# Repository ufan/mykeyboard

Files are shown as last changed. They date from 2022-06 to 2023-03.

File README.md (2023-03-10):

# A collection of designed keyboards #
## Features
All keyboards are powered by [zmk](https://zmk.dev/) with following design goals:
- portability
- minimalism
- ergonomic
- yet still powerful

## Super-powerful trackball firmware
- [youtube trackball demo](https://www.youtube.com/watch?v=7J-NTVMHwWQ&t=86s)
- [pmw3610_breakout pcb](https://github.com/ufan/pmw3610_breakout)
- [firmware support](https://github.com/ufan/zmk/tree/ptdevice-refactor)

# 42-key classic Corne-Pro with EPD display
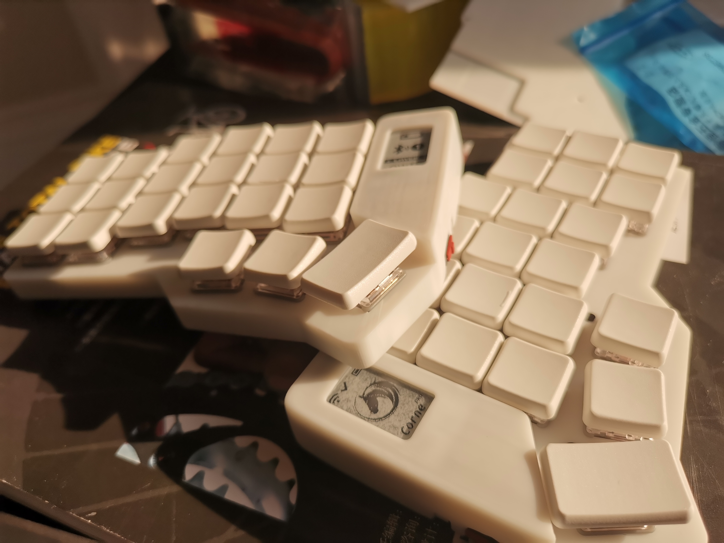
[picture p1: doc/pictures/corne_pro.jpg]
corne_pro


# 34-key Sweep-Pro with horizontal encoders
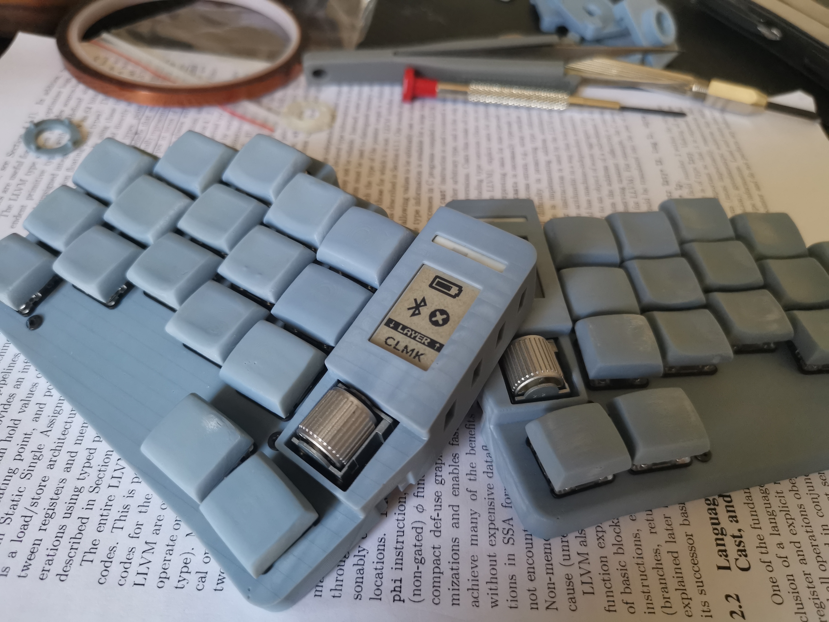
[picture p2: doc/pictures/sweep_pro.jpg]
sweep_pro


# 32-key Blade with a mini-trackball and a touchbar
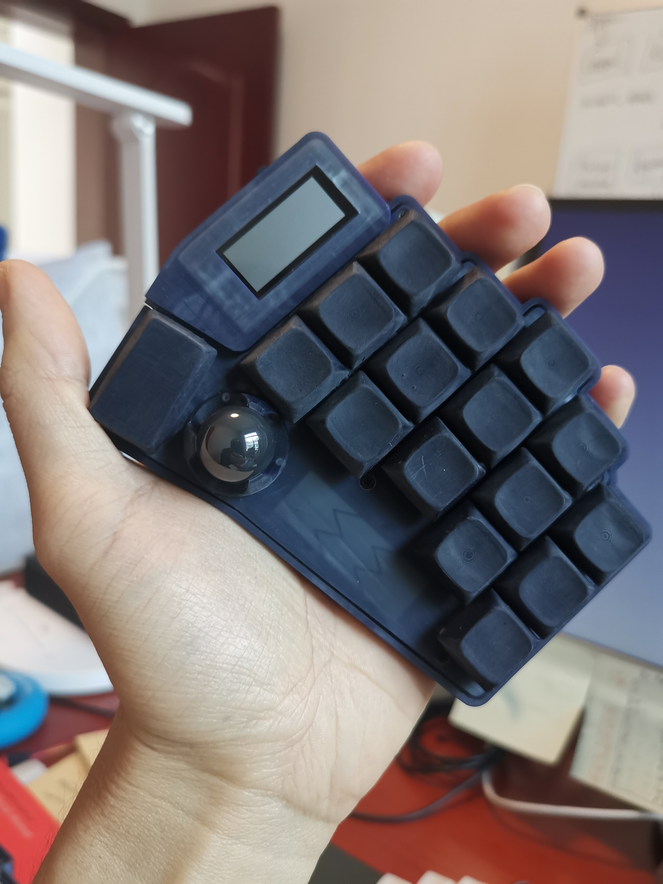
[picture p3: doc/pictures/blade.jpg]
blade


# Customizable logo display
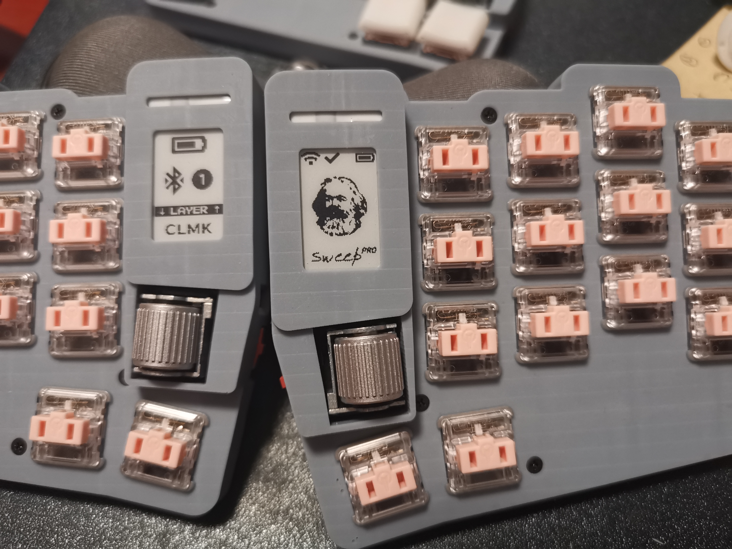
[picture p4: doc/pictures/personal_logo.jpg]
persoal_logo


# Wireless charging option
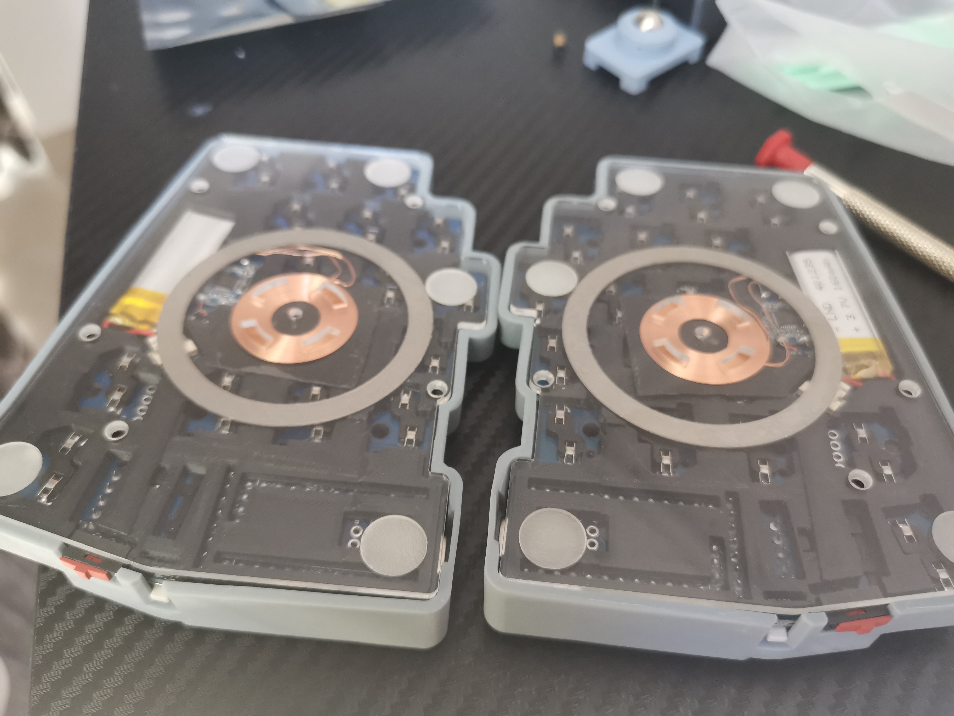
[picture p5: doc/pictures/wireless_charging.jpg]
wireless_charging


# Tenting support
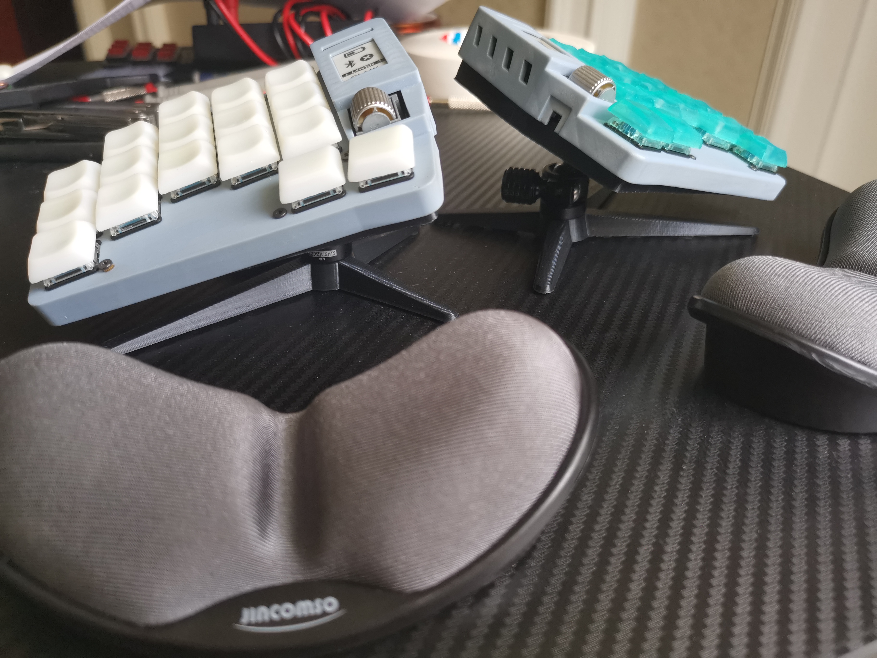
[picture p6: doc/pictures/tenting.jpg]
tenting


# Extensible
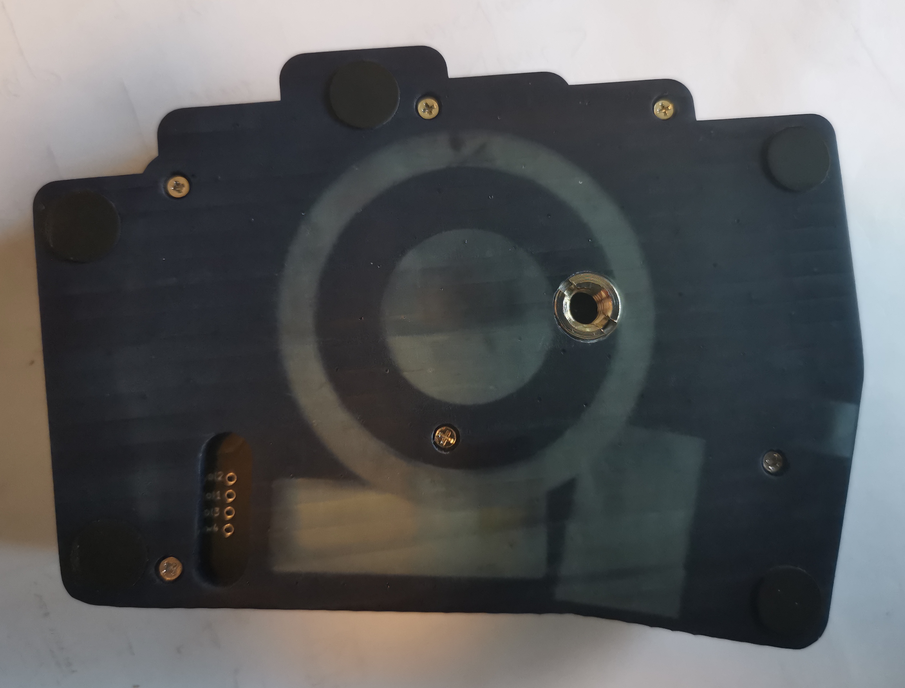
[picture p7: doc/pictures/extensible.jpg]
extensible


# 3D-printed concave/convex keycaps
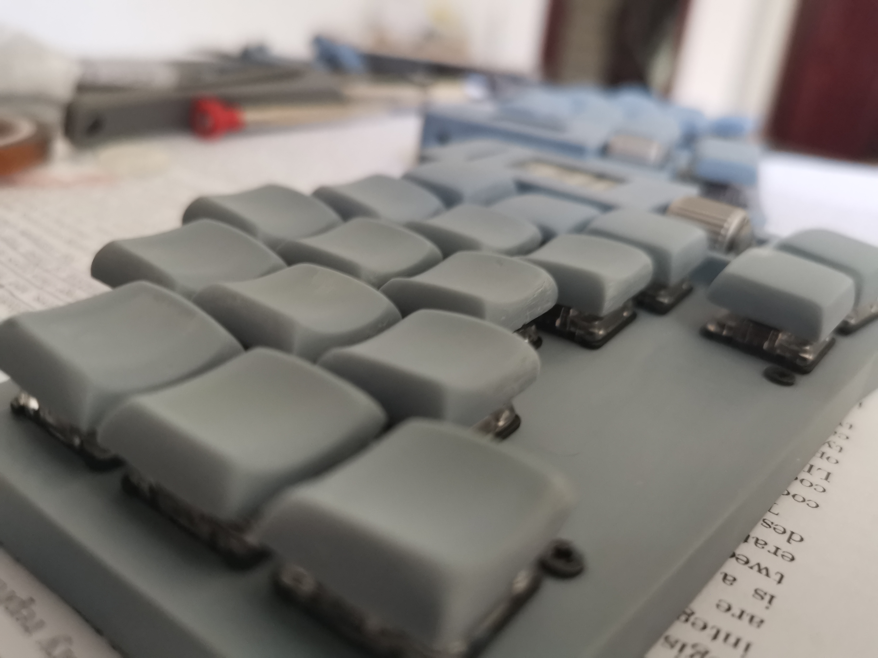
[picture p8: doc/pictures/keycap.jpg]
keycaps


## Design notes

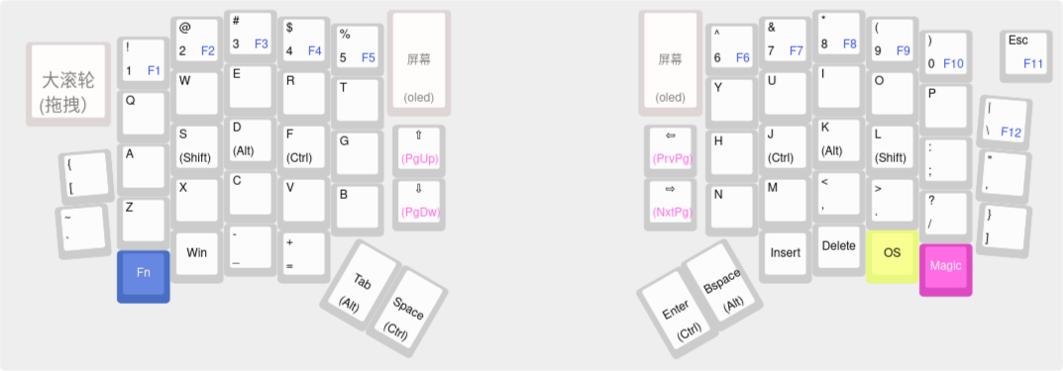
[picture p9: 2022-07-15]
doc/palm180/keyboard-layout.png

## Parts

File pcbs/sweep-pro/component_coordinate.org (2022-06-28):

* coordinates of each footprint
|                 |     left_x |    left_y |    delta_x |   delta_y |   right_x |   right_y |  angle |
|-----------------+------------+-----------+------------+-----------+-----------+-----------+--------|
| reference point |        212 |     43.75 |          0 |        0. | 82.754568 |     46.11 |        |
| pro micro       |        201 |    60.175 |        -11 |    16.425 | 93.754568 |    62.535 |        |
| display         |        201 |    79.275 |        -11 |    35.525 | 93.754568 |    81.635 |        |
| encoder         | 199.321127 | 93.163087 | -12.678873 | 49.413087 | 95.433441 | 95.523087 |    -95 |
| power_switch    |      209.7 |      96.9 |       -2.3 |     53.15 | 85.054568 |     99.26 | -103.4 |
| reset_button    |    211.825 |     86.45 |     -0.175 |      42.7 | 82.929568 |     88.81 |    -95 |
| sw1             |        107 |        67 |       -105 |     23.25 | 187.75457 |     69.36 |        |
| sw2             |        125 |        55 |        -87 |     11.25 | 169.75457 |     57.36 |        |
| sw3             |        143 |        48 |        -69 |      4.25 | 151.75457 |     50.36 |        |
| sw4             |        161 |      53.5 |        -51 |      9.75 | 133.75457 |     55.86 |        |
| sw5             |        179 |        56 |        -33 |     12.25 | 115.75457 |     58.36 |        |
| sw6             |        107 |        84 |       -105 |     40.25 | 187.75457 |     86.36 |        |
| sw7             |        125 |        72 |        -87 |     28.25 | 169.75457 |     74.36 |        |
| sw8             |        143 |        65 |        -69 |     21.25 | 151.75457 |     67.36 |        |
| sw9             |        161 |      70.5 |        -51 |     26.75 | 133.75457 |     72.86 |        |
| sw10            |        179 |        73 |        -33 |     29.25 | 115.75457 |     75.36 |        |
| sw11            |        107 |       101 |       -105 |     57.25 | 187.75457 |    103.36 |        |
| sw12            |        125 |        89 |        -87 |     45.25 | 169.75457 |     91.36 |        |
| sw13            |        143 |        82 |        -69 |     38.25 | 151.75457 |     84.36 |        |
| sw14            |        161 |      87.5 |        -51 |     43.75 | 133.75457 |     89.86 |        |
| sw15            |        179 |        90 |        -33 |     46.25 | 115.75457 |     92.36 |        |
| sw16            | 176.407158 |    110.95 | -35.592842 |      67.2 | 118.34741 |    113.31 |     -5 |
| sw17            | 195.367403 |    114.55 | -16.632597 |      70.8 | 99.387165 |    116.91 |    -13 |
| h1              |        115 |      57.5 |        -97 |     13.75 | 179.75457 |     59.86 |        |
| h2              |      171.2 |    46.425 |      -40.8 |     2.675 | 123.55457 |    48.785 |        |
| h3              |      187.3 |     101.6 |      -24.7 |     57.85 | 107.45457 |    103.96 |        |
| h4              |     116.95 |    108.15 |     -95.05 |      64.4 | 177.80457 |    110.51 |        |
| h5              |     165.35 |    114.93 |     -46.65 |     71.18 | 129.40457 |    117.29 |        |
| battery_switch  |      209.7 |      96.9 |       -2.3 |     53.15 | 85.054568 |     99.26 |    -103.4  |
| battery_con     |        167 |        99 |        -45 |     55.25 | 127.75457 |    101.36 |    130 |
| coil_con        |     155.85 |    98.025 |     -56.15 |    54.275 | 138.90457 |   100.385 | -98    |
| pogopin-1       |     202.54 |        53 |      -9.46 |      9.25 | 92.214568 |     55.36 |        |
| pogopin-2       |        200 |        53 |        -12 |      9.25 | 94.754568 |     55.36 |        |
| pogopin-3       |    178.625 |    100.35 |    -33.375 |      56.6 | 116.12957 |    102.71 |        |
#+TBLFM: $4=$2-@2$2::$5=$3-@2$3::$6=-$4+82.754568::$7=$5+46.11

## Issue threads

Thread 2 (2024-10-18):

A question about the pmw3610 cpi configuration.

klesh, 2024-10-18:
Hi, sorry to disturb you.

 I am working on porting the PMW3610 driver to QMK based on your implementation on https://github.com/ufan/zmk/tree/ptdevice-refactor/app/drivers/sensor/pixart/pmw3610
Your code looks solid and the mouse movement is working.
However, the `set_cpi` doesn't work on my side, I checked and rewrote the code many times and it just doesn't seem to be working 😂.
I don't know what to do next, mainly because I don't know how to verify if the CPI was configured correctly, here were my thoughts:
1. I suppose the cursor should move faster when the CPI is cranked up, but it didn't, the movement feels the same to me
2. Or I can read the sensor register to verify, but I don't know how to do so, because the datasheet doesn't mention it at all...

I wonder if you could help me with the following questions:

- Is `set_cpi` function working correctly for you? if so, is it moving faster when the CPI is higher?
- Do you know how to read the CPI register?
- I am designing a trackball using a snooker ball, when I roll the ball for a while, it would stop for few second then move again... like it needs a break or something, do you know why?

Here is my code if you would like to take a look:
https://github.com/klesh/vial-qmk/commit/7ee1826e2ec4768d11cb37462bd6b3debae2f722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

I am posting the issue here because `issues` on your `zmk` repo is disabled, hope you don't mind, and feel free to close it if you don't like it.

Thanks in advance.

klesh, 2024-10-18:
Ahh, I figured out what was wrong with the `set_cpi` code.

ufan, 2024-10-21:
Seems you've solved the problem. I did not test this function thoroughly. Did you mind posting a link to the corrected code?

klesh, 2024-10-21:
Sure, here you are. It is working nicely on my side:
https://github.com/klesh/vial-qmk/blob/319a4dc4122595aa557ad234925175cfb327d24c/drivers/sensors/pmw3610.c#L238

And I fixed the "cursor stop moving randomly" problem by forcing the sensor into awake mode
https://github.com/klesh/vial-qmk/blob/319a4dc4122595aa557ad234925175cfb327d24c/drivers/sensors/pmw3610.c#L238

Now, It is working fine most of the time. However, the cursor movement still goes haywire(moving slowly and flicking) sometimes, and I have to reset the MUC for it to work again. 😂

bullwinkle3000, 2024-12-05:
Hey there!  Curious if you got the haywire thing addressed at all?  Tested a bit on my side, and it seems to generally work well.

klesh, 2024-12-09:
@bullwinkle3000 I am not quite sure, but it seems like the haywire was caused by the hardware damage. Maybe I overheated them during the soldering.

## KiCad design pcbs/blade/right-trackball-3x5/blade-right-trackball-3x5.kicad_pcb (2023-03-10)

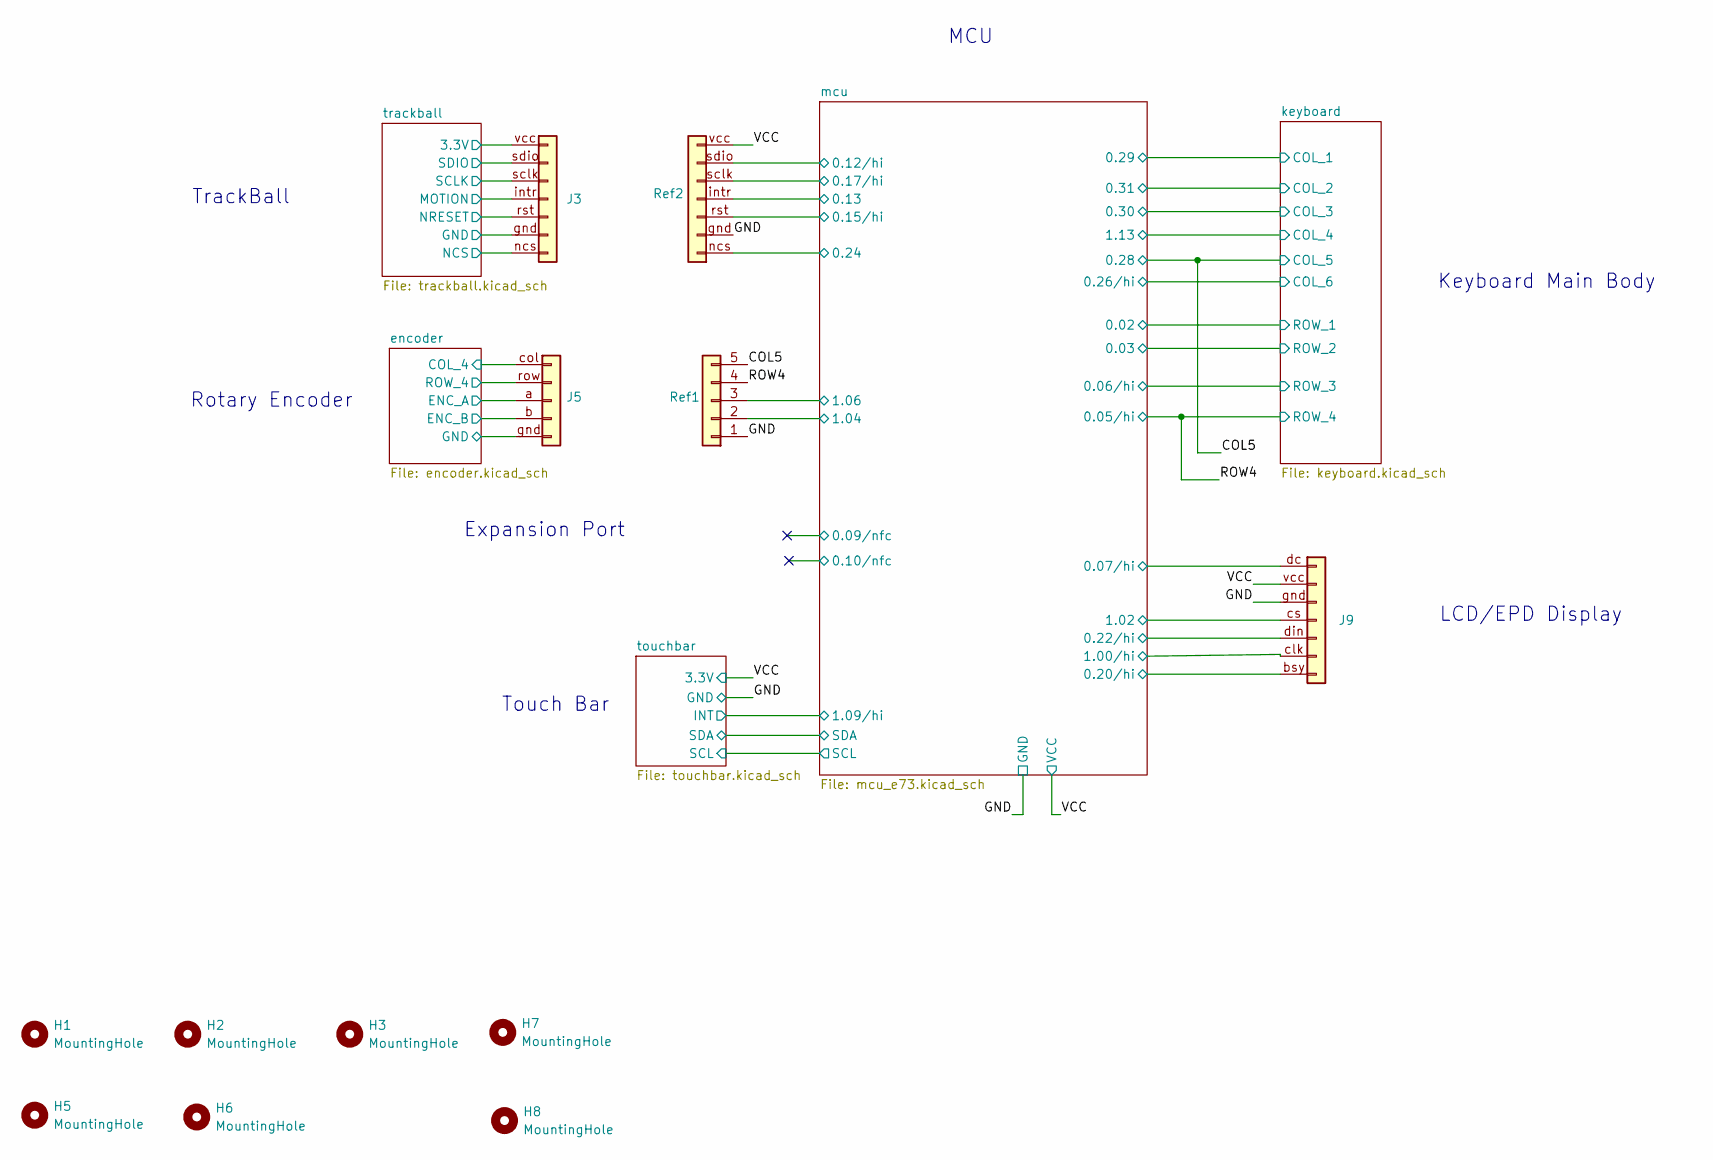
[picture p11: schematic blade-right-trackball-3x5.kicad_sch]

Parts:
H1, H2, H3, H5, H6, H7: MountingHole; MountingHole_3.2mm_M3_DIN965
H8: MountingHole; MountingHole_2mm
J3: Conn_01x07; PMW3610-Ref-Male
J5: Conn_01x05; Panasonic_EVQWGD001_Ref_Male
J9: Conn_Display_general; Conn_Display_MountHole
Ref1: Conn_01x05; Panasonic_EVQWGD001_Ref
Ref2: Conn_1x07; PMW3610-Ref

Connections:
/COL5: Ref1.5; also elsewhere on the board
/ROW4: Ref1.4; also elsewhere on the board
/VCC: J9.vcc, Ref2.vcc; also elsewhere on the board
/encoder/COL_4: J5.col; also elsewhere on the board
/encoder/ENC_A: J5.a; also elsewhere on the board
/encoder/ENC_B: J5.b; also elsewhere on the board
/encoder/GND: J5.gnd; also elsewhere on the board
/encoder/ROW_4: J5.row; also elsewhere on the board
/mcu/0.07/hi: J9.dc; also elsewhere on the board
/mcu/0.12/hi: Ref2.sdio; also elsewhere on the board
/mcu/0.13: Ref2.intr (motion); also elsewhere on the board
/mcu/0.15/hi: Ref2.rst; also elsewhere on the board
/mcu/0.17/hi: Ref2.sclk; also elsewhere on the board
/mcu/0.20/hi: J9.bsy; also elsewhere on the board
/mcu/0.22/hi: J9.din; also elsewhere on the board
/mcu/0.24: Ref2.ncs; also elsewhere on the board
/mcu/1.00/hi: J9.clk; also elsewhere on the board
/mcu/1.02: J9.cs; also elsewhere on the board
/mcu/1.04: Ref1.2; also elsewhere on the board
/mcu/1.06: Ref1.3; also elsewhere on the board
/trackball/3.3V: J3.vcc; also elsewhere on the board
/trackball/GND: J3.gnd; also elsewhere on the board
/trackball/MOTION: J3.intr (motion); also elsewhere on the board
/trackball/NCS: J3.ncs; also elsewhere on the board
/trackball/NRESET: J3.rst; also elsewhere on the board
/trackball/SCLK: J3.sclk; also elsewhere on the board
/trackball/SDIO: J3.sdio; also elsewhere on the board
GND: J9.gnd, Ref1.1, Ref2.gnd; also elsewhere on the board

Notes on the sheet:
Touch Bar
Rotary Encoder
LCD/EPD Display
Keyboard Main Body
Expansion Port
TrackBall
MCU

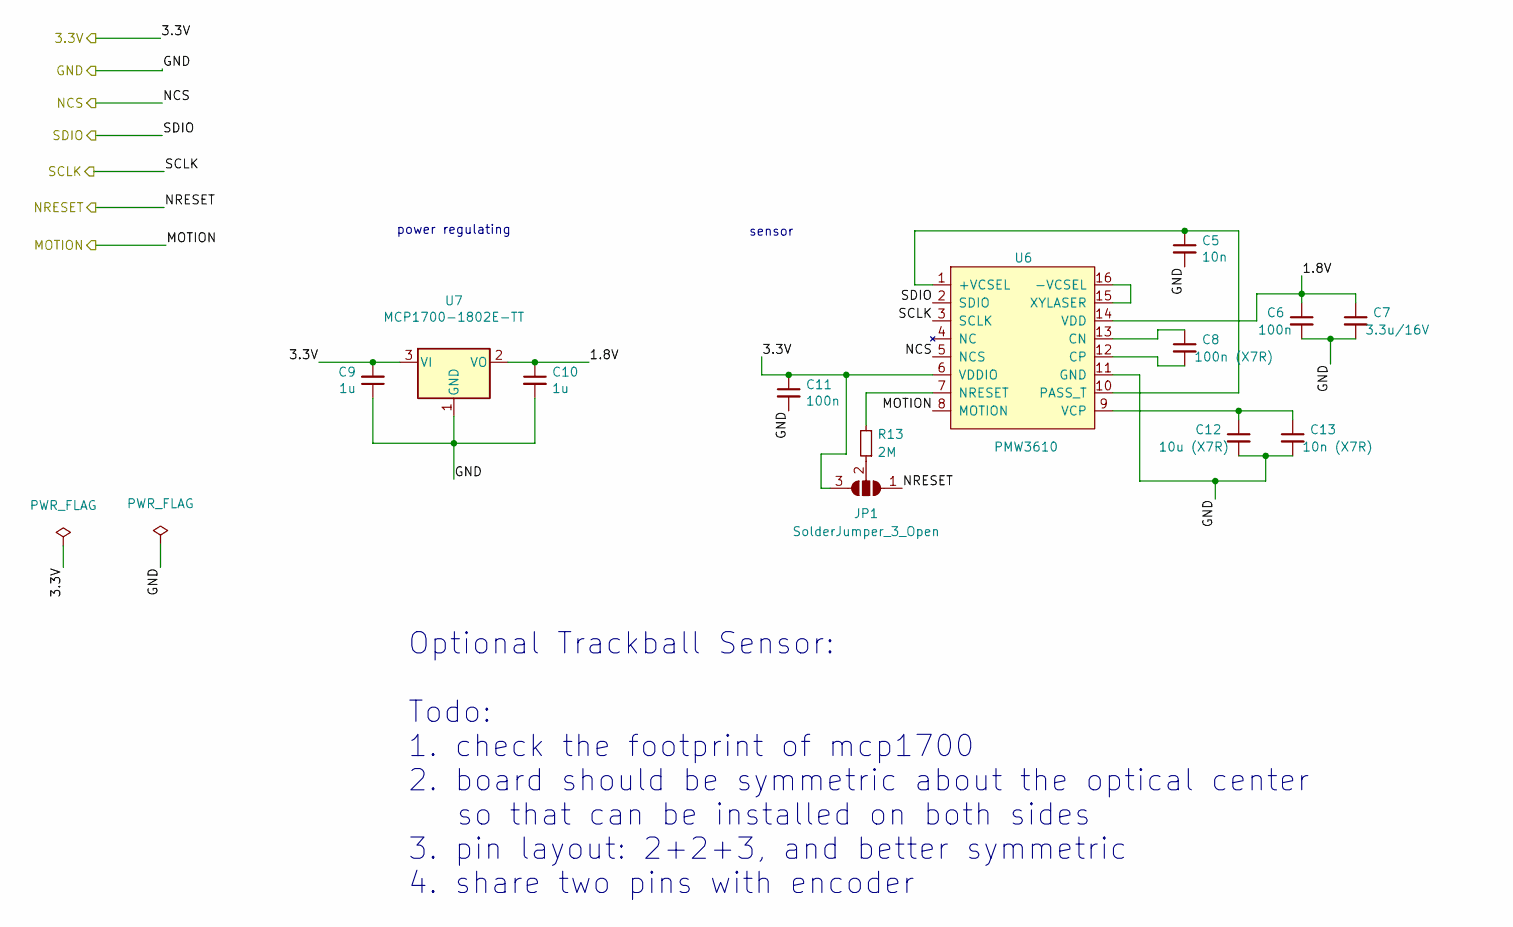
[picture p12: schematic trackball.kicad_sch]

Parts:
C5: 10n; C_0603_1608Metric; LCSC C19666
C6, C11: 100n; C_0603_1608Metric; LCSC C19666
C7: 3.3u/16V; C_0603_1608Metric; LCSC C19666
C8: 100n (X7R); C_0603_1608Metric; LCSC C19666
C9: 1u; C_0603_1608Metric; LCSC C14663
C10: 1u; C_0603_1608Metric; LCSC C15849
C12: 10u (X7R); C_0603_1608Metric; LCSC C19666
C13: 10n (X7R); C_0603_1608Metric; LCSC C19666
JP1: SolderJumper_3_Open; SolderJumper-3_P1.3mm_Open_RoundedPad1.0x1.5mm_NumberLabels
R13: 2M; R_0603_1608Metric
U6: PMW3610
U7: MCP1700-1802E-TT; SOT-23

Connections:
/trackball/1.8V: C6.1, C7.1, C10.1, U6.14 (VDD), U7.2 (VO)
/trackball/3.3V: C9.2, C11.1, JP1.3 (B), U6.6 (VDDIO), U7.3 (VI); also elsewhere on the board
/trackball/GND: C5.2, C6.2, C7.2, C9.1, C10.2, C11.2, C12.2, C13.2, U6.11 (GND), U7.1 (GND); also elsewhere on the board
/trackball/MOTION: U6.8 (MOTION); also elsewhere on the board
/trackball/NCS: U6.5 (NCS); also elsewhere on the board
/trackball/NRESET: JP1.1 (A); also elsewhere on the board
/trackball/SCLK: U6.3 (SCLK); also elsewhere on the board
/trackball/SDIO: U6.2 (SDIO); also elsewhere on the board
unnamed: C5.1, U6.1 (+VCSEL), U6.10 (PASS_T)
unnamed: C8.1, U6.13 (CN)
unnamed: C8.2, U6.12 (CP)
unnamed: C12.1, C13.1, U6.9 (VCP)
unnamed: JP1.2 (C), R13.1
unnamed: R13.2, U6.7 (NRESET)
unnamed: U6.15 (XYLASER), U6.16 (-VCSEL)

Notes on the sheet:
Optional Trackball Sensor: Todo: 1. check the footprint of mcp1700 2. board should be symmetric about the optical center so that can be installed on both sides 3. pin layout: 2+2+3, and better symmetric 4. share two pins with encoder
sensor
power regulating

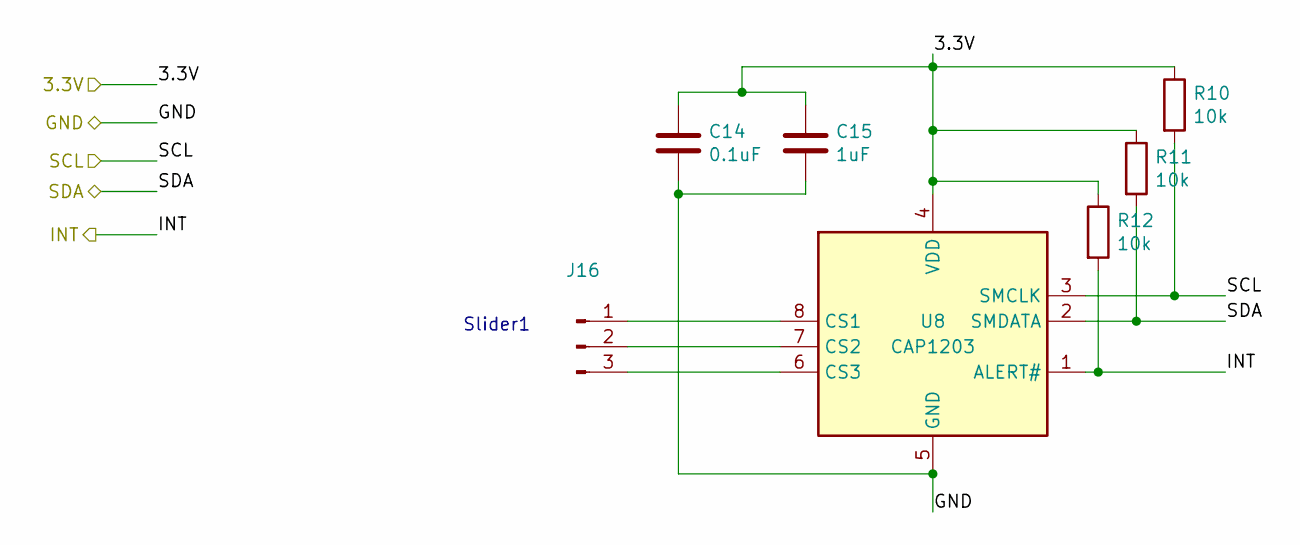
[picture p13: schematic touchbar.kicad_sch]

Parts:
C14: 0.1uF; C_0603_1608Metric
C15: 1uF; C_0603_1608Metric
J16: Conn_01x03_Male; TouchSlider-3_36x12mm
R10, R11, R12: 10k; R_0603_1608Metric
U8: CAP1203; SOIC-8_3.9x4.9mm_P1.27mm

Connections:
/VCC: C14.1, C15.1, R10.1, R11.1, R12.1, U8.4 (VDD); also elsewhere on the board
/mcu/SCL: R10.2, U8.3 (SMCLK); also elsewhere on the board
/mcu/SDA: R11.2, U8.2 (SMDATA); also elsewhere on the board
/touchbar/INT: R12.2, U8.1 (ALERT#); also elsewhere on the board
GND: C14.2, C15.2, U8.5 (GND); also elsewhere on the board
unnamed: J16.1, U8.8 (CS1)
unnamed: J16.2, U8.7 (CS2)
unnamed: J16.3, U8.6 (CS3)

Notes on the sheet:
Slider1

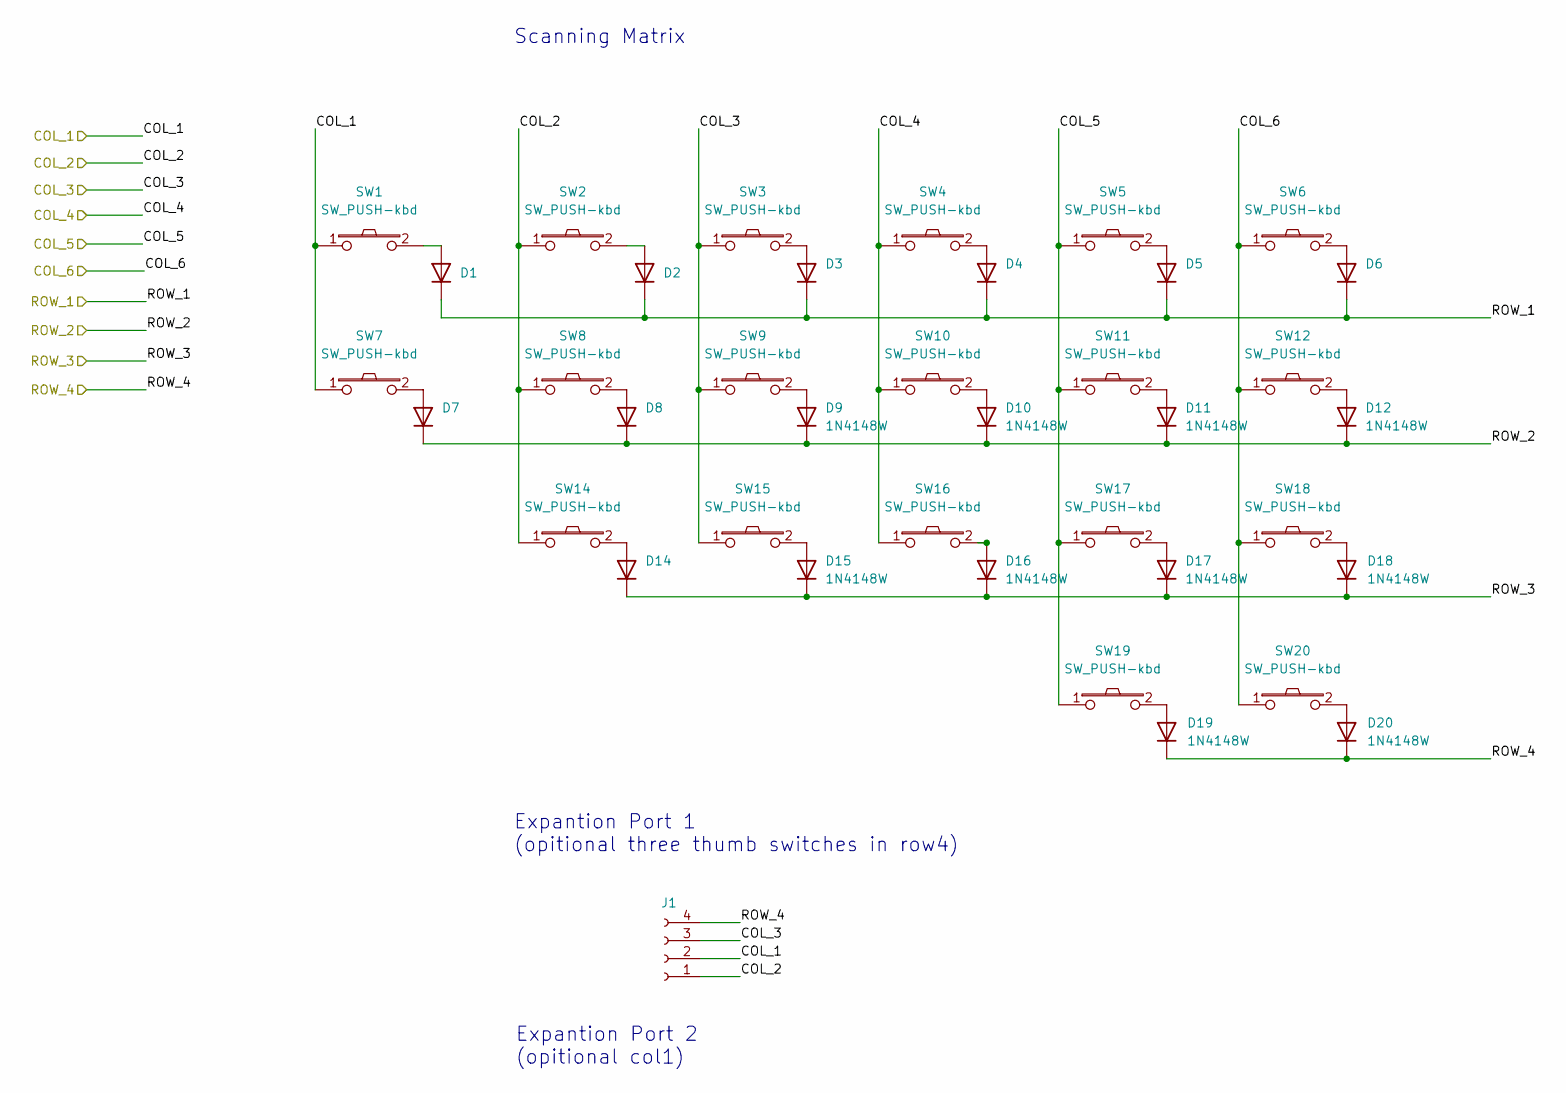
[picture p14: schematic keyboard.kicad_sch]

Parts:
D1, D2, D3, D4, D5, D6, D7, D8, D9, D10, D11, D12, D14, D15, D16, D17, D18, D19, D20: 1N4148W; Diode
J1: expantion1; Magnetic-PogoPin-1x04-Female
SW1, SW2, SW3, SW4, SW5, SW6, SW7, SW8, SW9, SW10, SW11, SW12, SW14, SW15, SW16, SW17, SW18, SW19, SW20: SW_PUSH-kbd; Kailh_Choc_Hotplug

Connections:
/COL5: SW5.1, SW11.1, SW17.1, SW19.1; also elsewhere on the board
/ROW4: D19.1 (K), D20.1 (K), J1.4; also elsewhere on the board
/keyboard/COL_1: J1.2, SW1.1, SW7.1; also elsewhere on the board
/keyboard/COL_2: J1.1, SW2.1, SW8.1, SW14.1; also elsewhere on the board
/keyboard/COL_3: J1.3, SW3.1, SW9.1, SW15.1; also elsewhere on the board
/keyboard/COL_4: SW4.1, SW10.1, SW16.1; also elsewhere on the board
/keyboard/COL_6: SW6.1, SW12.1, SW18.1, SW20.1; also elsewhere on the board
/keyboard/ROW_1: D1.1 (K), D2.1 (K), D3.1 (K), D4.1 (K), D5.1 (K), D6.1 (K); also elsewhere on the board
/keyboard/ROW_2: D7.1 (K), D8.1 (K), D9.1 (K), D10.1 (K), D11.1 (K), D12.1 (K); also elsewhere on the board
/keyboard/ROW_3: D14.1 (K), D15.1 (K), D16.1 (K), D17.1 (K), D18.1 (K); also elsewhere on the board
unnamed: D1.2 (A), SW1.2
unnamed: D2.2 (A), SW2.2
unnamed: D3.2 (A), SW3.2
unnamed: D4.2 (A), SW4.2
unnamed: D5.2 (A), SW5.2
unnamed: D6.2 (A), SW6.2
unnamed: D7.2 (A), SW7.2
unnamed: D8.2 (A), SW8.2
unnamed: D9.2 (A), SW9.2
unnamed: D10.2 (A), SW10.2
unnamed: D11.2 (A), SW11.2
unnamed: D12.2 (A), SW12.2
unnamed: D14.2 (A), SW14.2
unnamed: D15.2 (A), SW15.2
unnamed: D16.2 (A), SW16.2
unnamed: D17.2 (A), SW17.2
unnamed: D18.2 (A), SW18.2
unnamed: D19.2 (A), SW19.2
unnamed: D20.2 (A), SW20.2

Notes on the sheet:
Scanning Matrix
Expantion Port 2 (opitional col1)
Expantion Port 1 (opitional three thumb switches in row4)

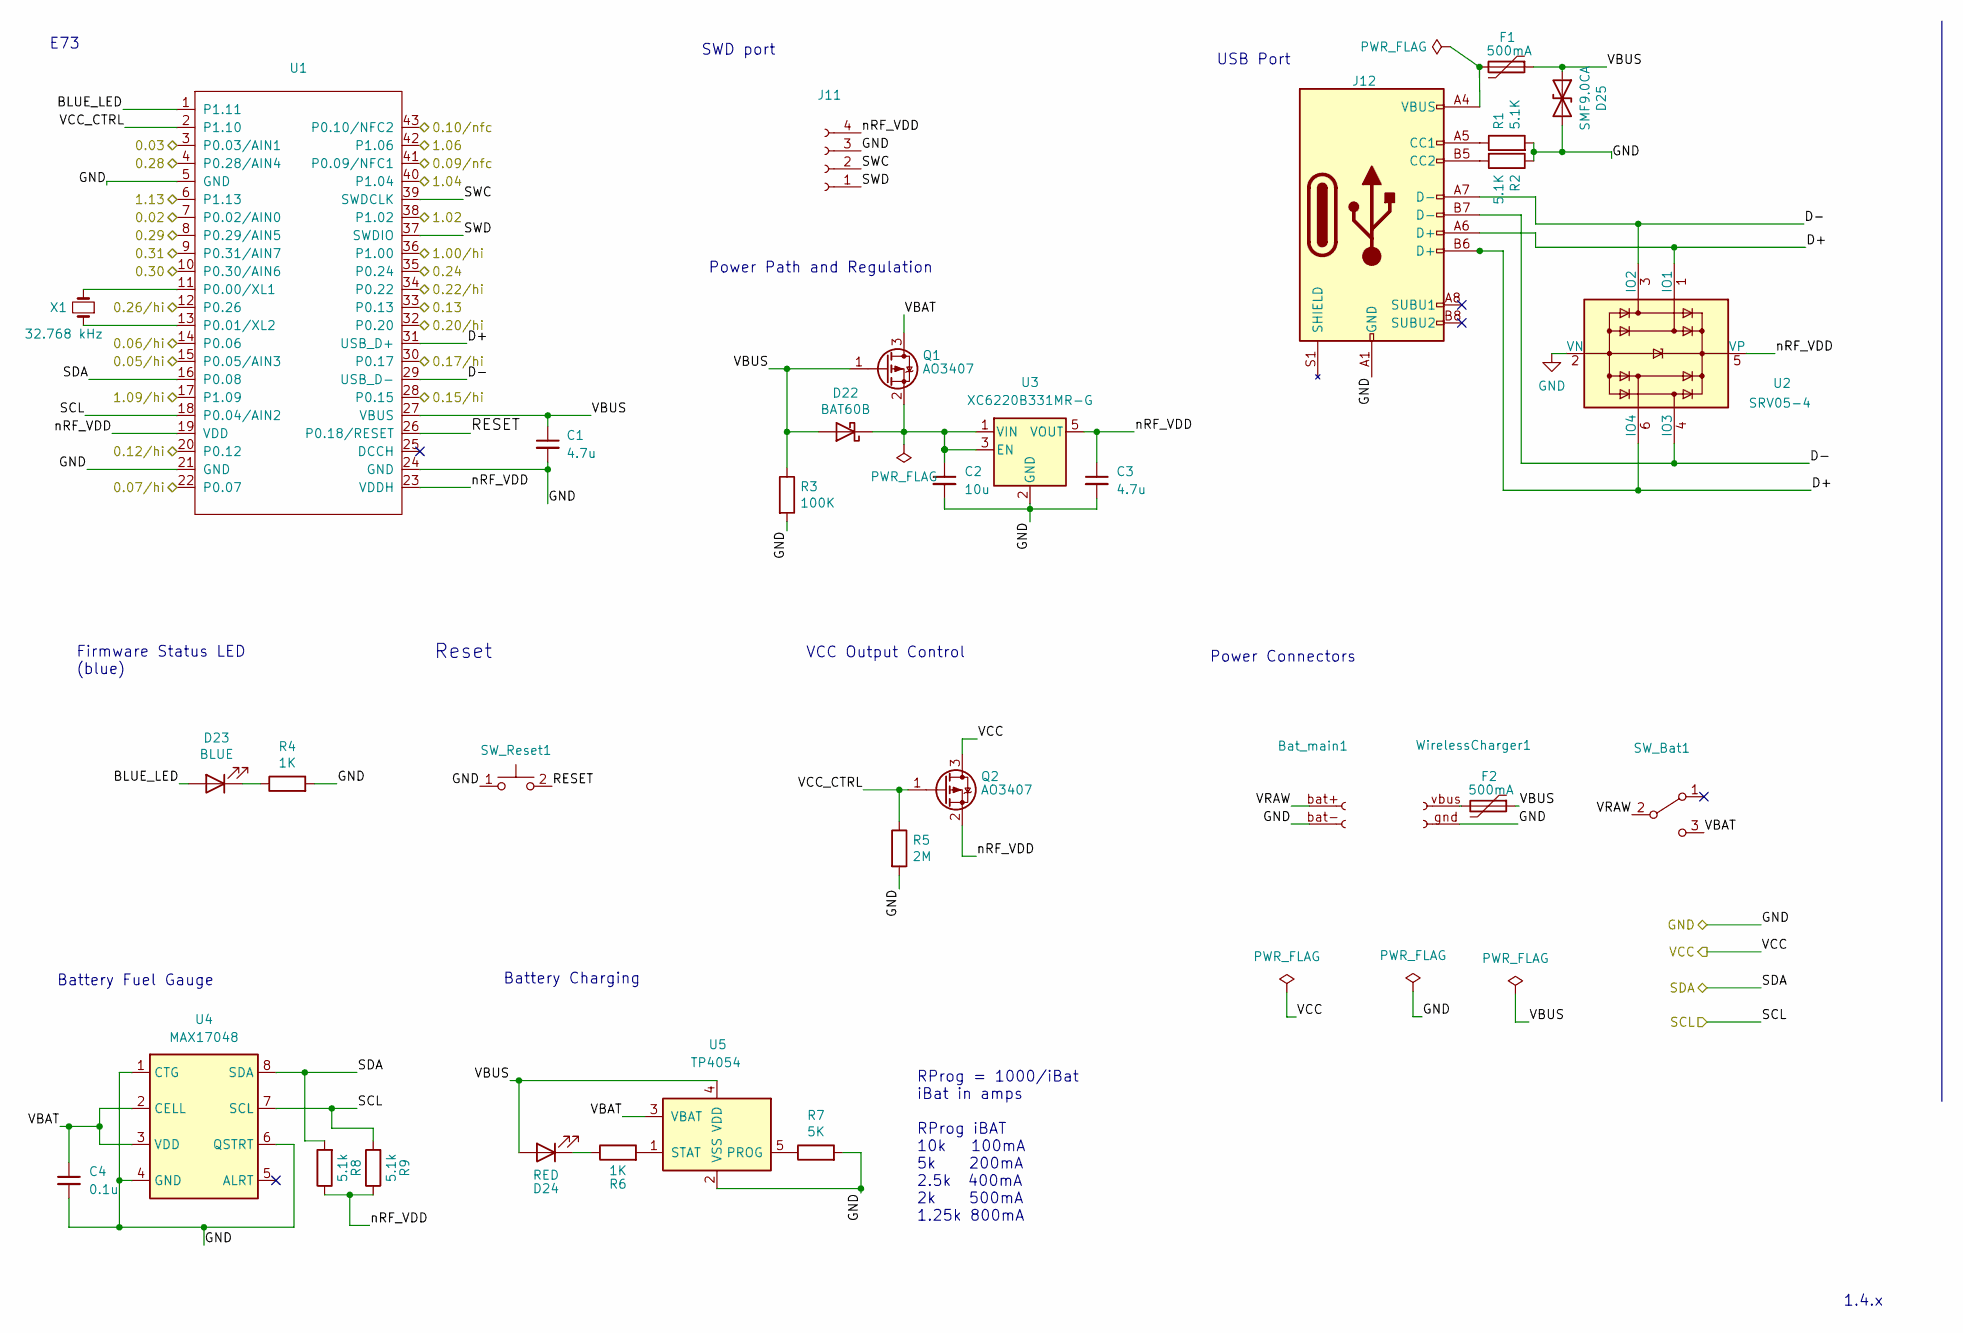
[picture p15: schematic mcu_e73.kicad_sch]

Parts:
Bat_main1: Conn_Battery_solderable; JST_ACH_BM02B-ACHSS-GAN-ETF_1x02-1MP_P1.20mm_Vertical
C1, C3: 4.7u; C_0603_1608Metric
C2: 10u; C_0603_1608Metric
C4: 0.1u; C_0603_1608Metric
D22: BAT60B; D_SOD-323
D23: BLUE; LED_0603_1608Metric
D24: RED; LED_0603_1608Metric
D25: SMF9.0CA; D_SOD-123F; Part Name Bidirectional Diode; LCSC Part C435473
F1, F2: 500mA; Fuse_1206_3216Metric; Part Name Polyfuse; LCSC Part C151162
J11: Conn_01x04_Female; PinHeader_1x04_P2.54mm_Vertical
J12: USB-C USB 2.0 MC-372; nrfmicro_USB-C_C168688
Q1, Q2: AO3407; SOT-23
R1, R2: 5.1K; R_0603_1608Metric
R3: 100K; R_0603_1608Metric
R4, R6: 1K; R_0603_1608Metric
R5: 2M; R_0603_1608Metric
R7: 5K; R_0603_1608Metric
R8, R9: 5.1k; R_0603_1608Metric
SW_Bat1: SW_Battery-kbd; SW_BSI10
SW_Reset1: SW_RESET-kbd; SW_Reset_vertical
U1: E73-2G4M08S1C; E73-2G4M08S1C-52840
U2: SRV05-4; Part Name TVS Diode Array; LCSC Part C558418
U3: XC6220B331MR-G; SOT-23-5
U4: MAX17048; MAX17048-TDFN-8-1EP_2x2mm_P0.5mm_EP0.8x1.2mm
U5: TP4054; SOT-23-5
WirelessCharger1: Conn_01x02_Female; JST_ACH_BM02B-ACHSS-GAN-ETF_1x02-1MP_P1.20mm_Vertical
X1: 32.768 kHz; Crystal_SMD_MicroCrystal_CM9V-T1A-2Pin_1.6x1.0mm

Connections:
/COL5: U1.4 (P0.28/AIN4); also elsewhere on the board
/ROW4: U1.15 (P0.05/AIN3); also elsewhere on the board
/VCC: Q2.3 (D); also elsewhere on the board
/keyboard/COL_1: U1.8 (P0.29/AIN5); also elsewhere on the board
/keyboard/COL_2: U1.9 (P0.31/AIN7); also elsewhere on the board
/keyboard/COL_3: U1.10 (P0.30/AIN6); also elsewhere on the board
/keyboard/COL_4: U1.6 (P1.13); also elsewhere on the board
/keyboard/COL_6: U1.12 (P0.26); also elsewhere on the board
/keyboard/ROW_1: U1.7 (P0.02/AIN0); also elsewhere on the board
/keyboard/ROW_2: U1.3 (P0.03/AIN1); also elsewhere on the board
/keyboard/ROW_3: U1.14 (P0.06); also elsewhere on the board
/mcu/0.07/hi: U1.22 (P0.07); also elsewhere on the board
/mcu/0.09/nfc: U1.41 (P0.09/NFC1)
/mcu/0.10/nfc: U1.43 (P0.10/NFC2)
/mcu/0.12/hi: U1.20 (P0.12); also elsewhere on the board
/mcu/0.13: U1.33 (P0.13); also elsewhere on the board
/mcu/0.15/hi: U1.28 (P0.15); also elsewhere on the board
/mcu/0.17/hi: U1.30 (P0.17); also elsewhere on the board
/mcu/0.20/hi: U1.32 (P0.20); also elsewhere on the board
/mcu/0.22/hi: U1.34 (P0.22); also elsewhere on the board
/mcu/0.24: U1.35 (P0.24); also elsewhere on the board
/mcu/1.00/hi: U1.36 (P1.00); also elsewhere on the board
/mcu/1.02: U1.38 (P1.02); also elsewhere on the board
/mcu/1.04: U1.40 (P1.04); also elsewhere on the board
/mcu/1.06: U1.42 (P1.06); also elsewhere on the board
/mcu/BLUE_LED: D23.2 (A), U1.1 (P1.11)
/mcu/D+: J12.A6 (D+), J12.B6 (D+), U1.31 (USB_D+), U2.1 (IO1), U2.6 (IO4)
/mcu/D-: J12.A7 (D-), J12.B7 (D-), U1.29 (USB_D-), U2.3 (IO2), U2.4 (IO3)
/mcu/RESET: SW_Reset1.2, U1.26 (P0.18/RESET)
/mcu/SCL: R9.2, U1.18 (P0.04/AIN2), U4.7 (SCL); also elsewhere on the board
/mcu/SDA: R8.2, U1.16 (P0.08), U4.8 (SDA); also elsewhere on the board
/mcu/SWC: J11.2, U1.39 (SWDCLK)
/mcu/SWD: J11.1, U1.37 (SWDIO)
/mcu/VBAT: C4.1, Q1.3 (D), SW_Bat1.3 (C), U4.2 (CELL), U4.3 (VDD), U5.3 (VBAT)
/mcu/VBUS: C1.1, D22.2 (A), D24.2 (A), D25.1 (A1), F1.1, F2.1, Q1.1 (G), R3.1, U1.27 (VBUS), U5.4 (VDD)
/mcu/VCC_CTRL: Q2.1 (G), R5.1, U1.2 (P1.10)
/mcu/VRAW: Bat_main1.bat+ (Bat+), SW_Bat1.2 (B)
/mcu/nRF_VDD: C3.1, J11.4, Q2.2 (S), R8.1, R9.1, U1.19 (VDD), U1.23 (VDDH), U2.5 (VP), U3.5 (VOUT)
/touchbar/INT: U1.17 (P1.09); also elsewhere on the board
GND: Bat_main1.bat- (Bat-), C1.2, C2.2, C3.2, C4.2, D25.2 (A2), J11.3, J12.A1 (GND), R1.2, R2.1, R3.2, R4.2, R5.2, R7.2, SW_Reset1.1, U1.5 (GND), U1.21 (GND), U1.24 (GND), U2.2 (VN), U3.2 (GND), U4.1 (CTG), U4.4 (GND), U4.6 (QSTRT), U5.2 (VSS), WirelessCharger1.gnd; also elsewhere on the board
unnamed: C2.1, D22.1 (K), Q1.2 (S), U3.1 (VIN), U3.3 (EN)
unnamed: D23.1 (K), R4.1
unnamed: D24.1 (K), R6.1
unnamed: F1.2, J12.A4 (VBUS)
unnamed: F2.2, WirelessCharger1.vbus
unnamed: J12.A5 (CC1), R1.1
unnamed: J12.B5 (CC2), R2.2
unnamed: R6.2, U5.1 (STAT)
unnamed: R7.1, U5.5 (PROG)
unnamed: U1.11 (P0.00/XL1), X1.2
unnamed: U1.13 (P0.01/XL2), X1.1

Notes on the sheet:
Battery Charging
Reset
Power Path and Regulation
RProg = 1000/iBat iBat in amps RProg iBAT 10k 100mA 5k 200mA 2.5k 400mA 2k 500mA 1.25k 800mA
1.4.x
USB Port
Battery Fuel Gauge
E73
VCC Output Control
Power Connectors
SWD port
Firmware Status LED (blue)

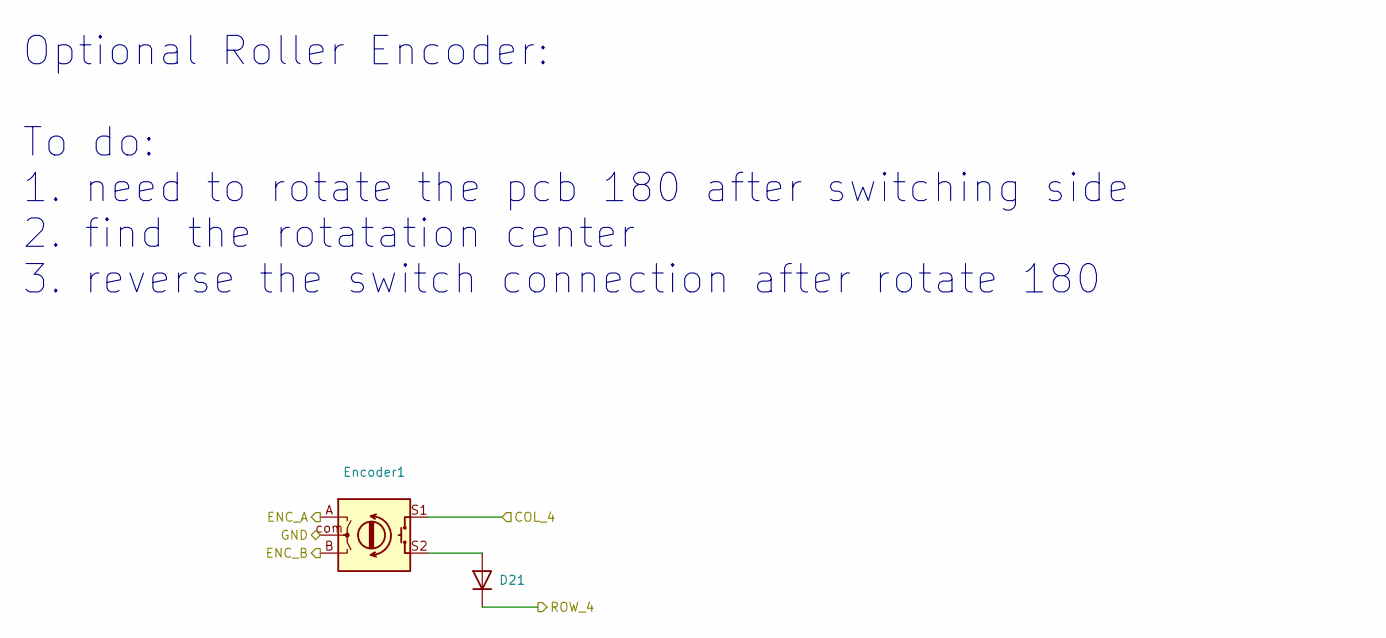
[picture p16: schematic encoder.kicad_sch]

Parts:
D21: 1N4148W; Diode
Encoder1: RotaryEncoder; Panasonic_EVQWGD001_Latest

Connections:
/encoder/COL_4: Encoder1.S1; also elsewhere on the board
/encoder/ENC_A: Encoder1.A; also elsewhere on the board
/encoder/ENC_B: Encoder1.B; also elsewhere on the board
/encoder/GND: Encoder1.com (COM); also elsewhere on the board
/encoder/ROW_4: D21.1 (K); also elsewhere on the board
unnamed: D21.2 (A), Encoder1.S2

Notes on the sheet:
Optional Roller Encoder: To do: 1. need to rotate the pcb 180 after switching side 2. find the rotatation center 3. reverse the switch connection after rotate 180

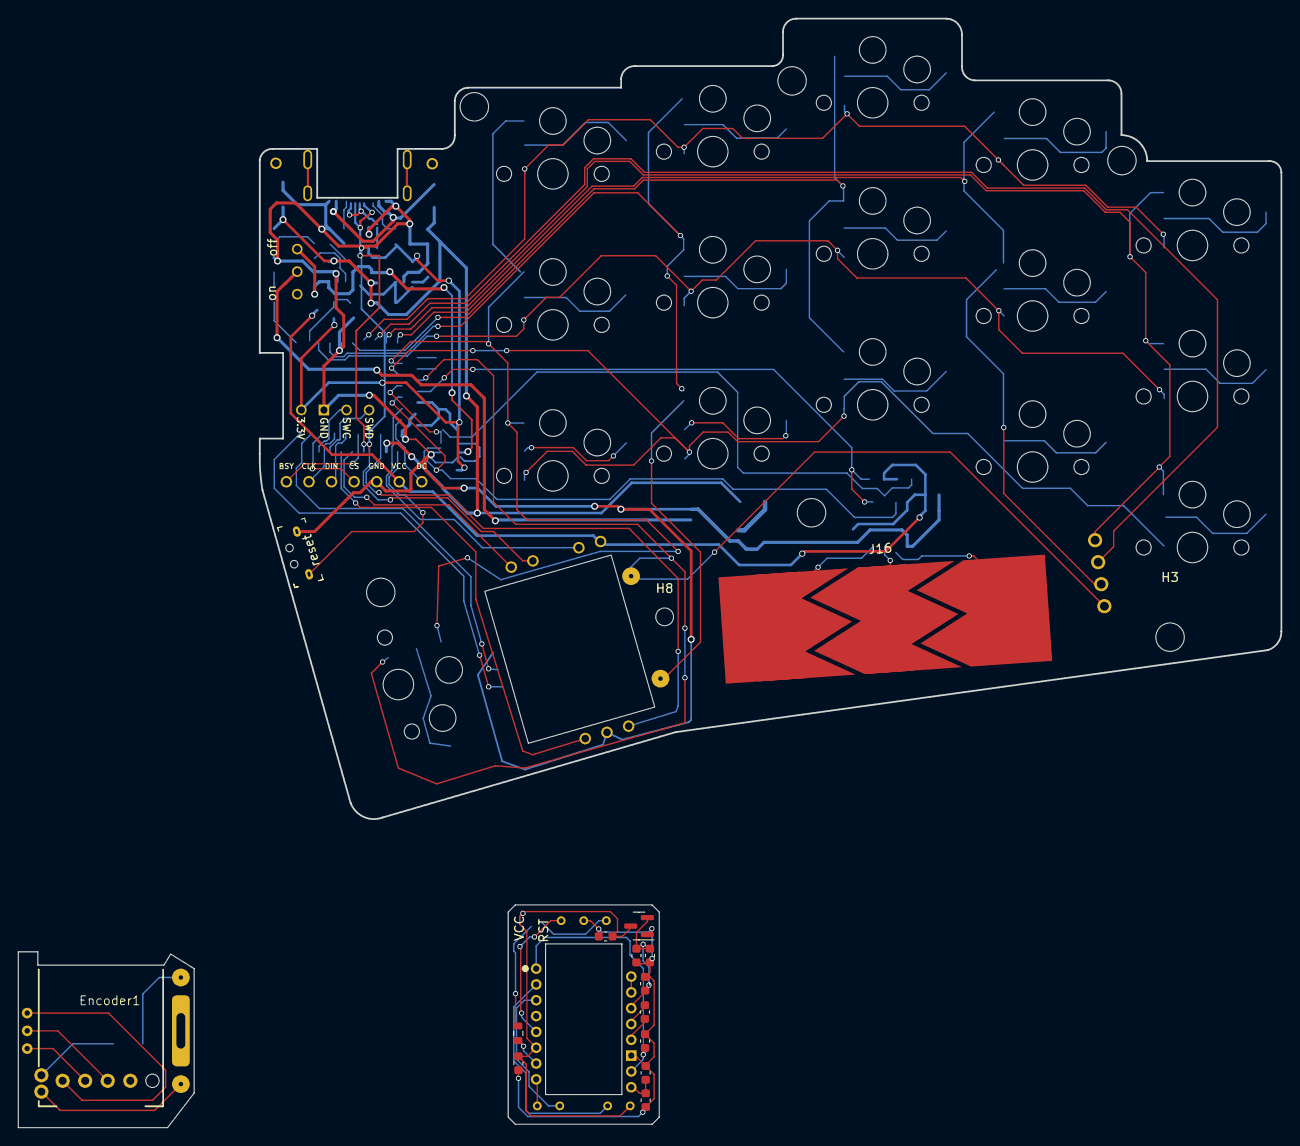
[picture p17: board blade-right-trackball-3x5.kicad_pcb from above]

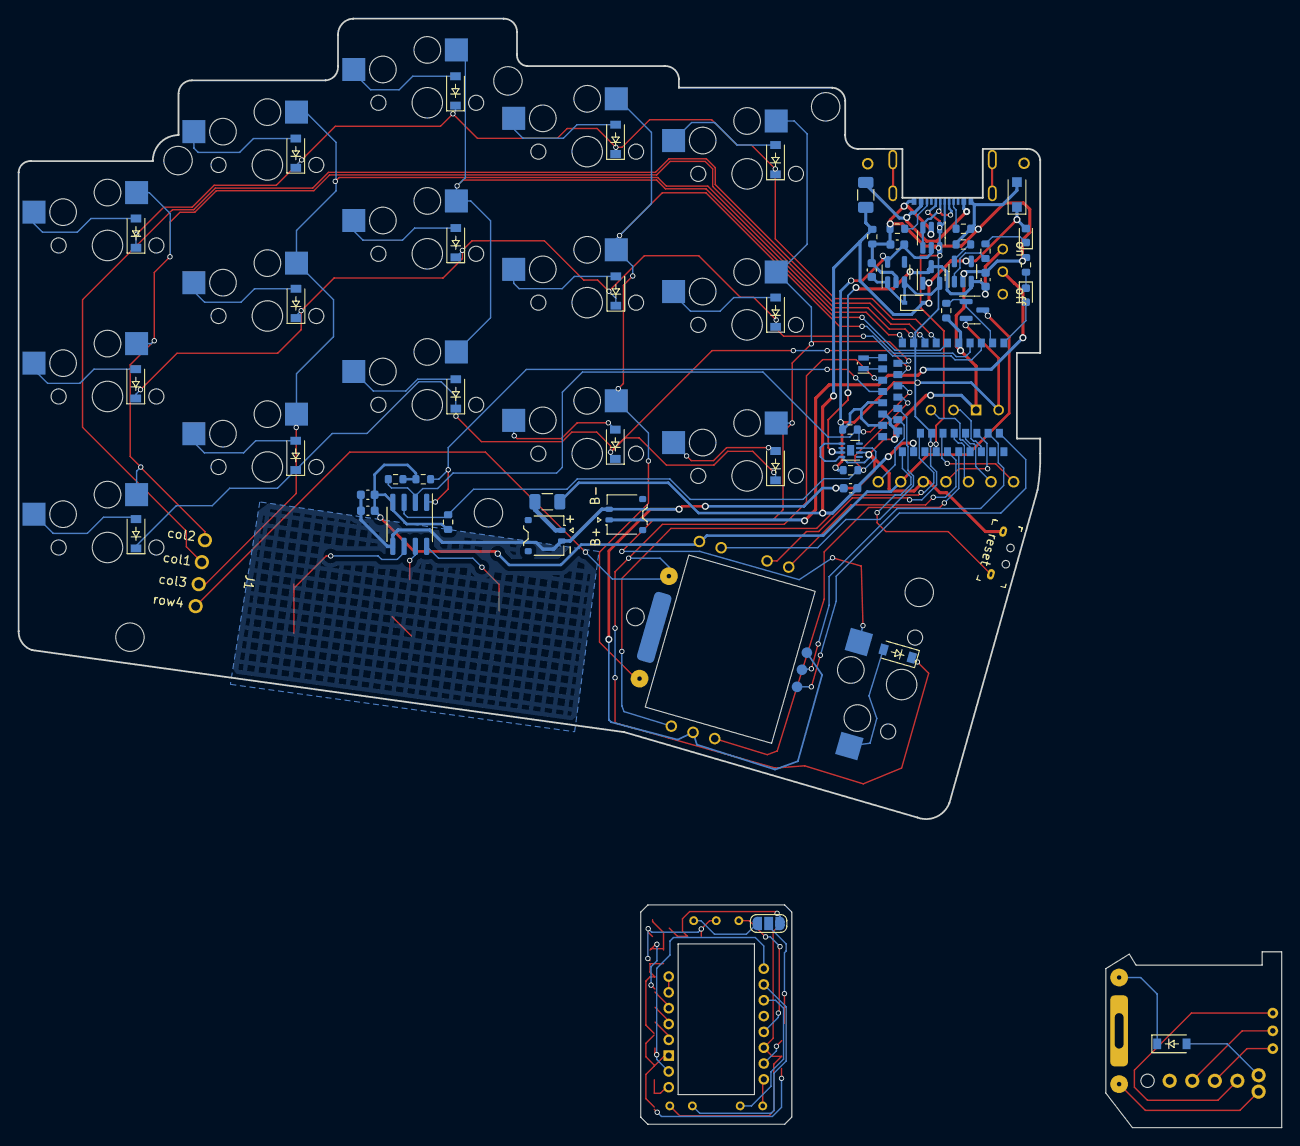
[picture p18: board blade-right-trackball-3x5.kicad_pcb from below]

Board: 2 copper layers, 115.0 x 90.1 mm, 100 parts (57 on the bottom side), 89 nets.

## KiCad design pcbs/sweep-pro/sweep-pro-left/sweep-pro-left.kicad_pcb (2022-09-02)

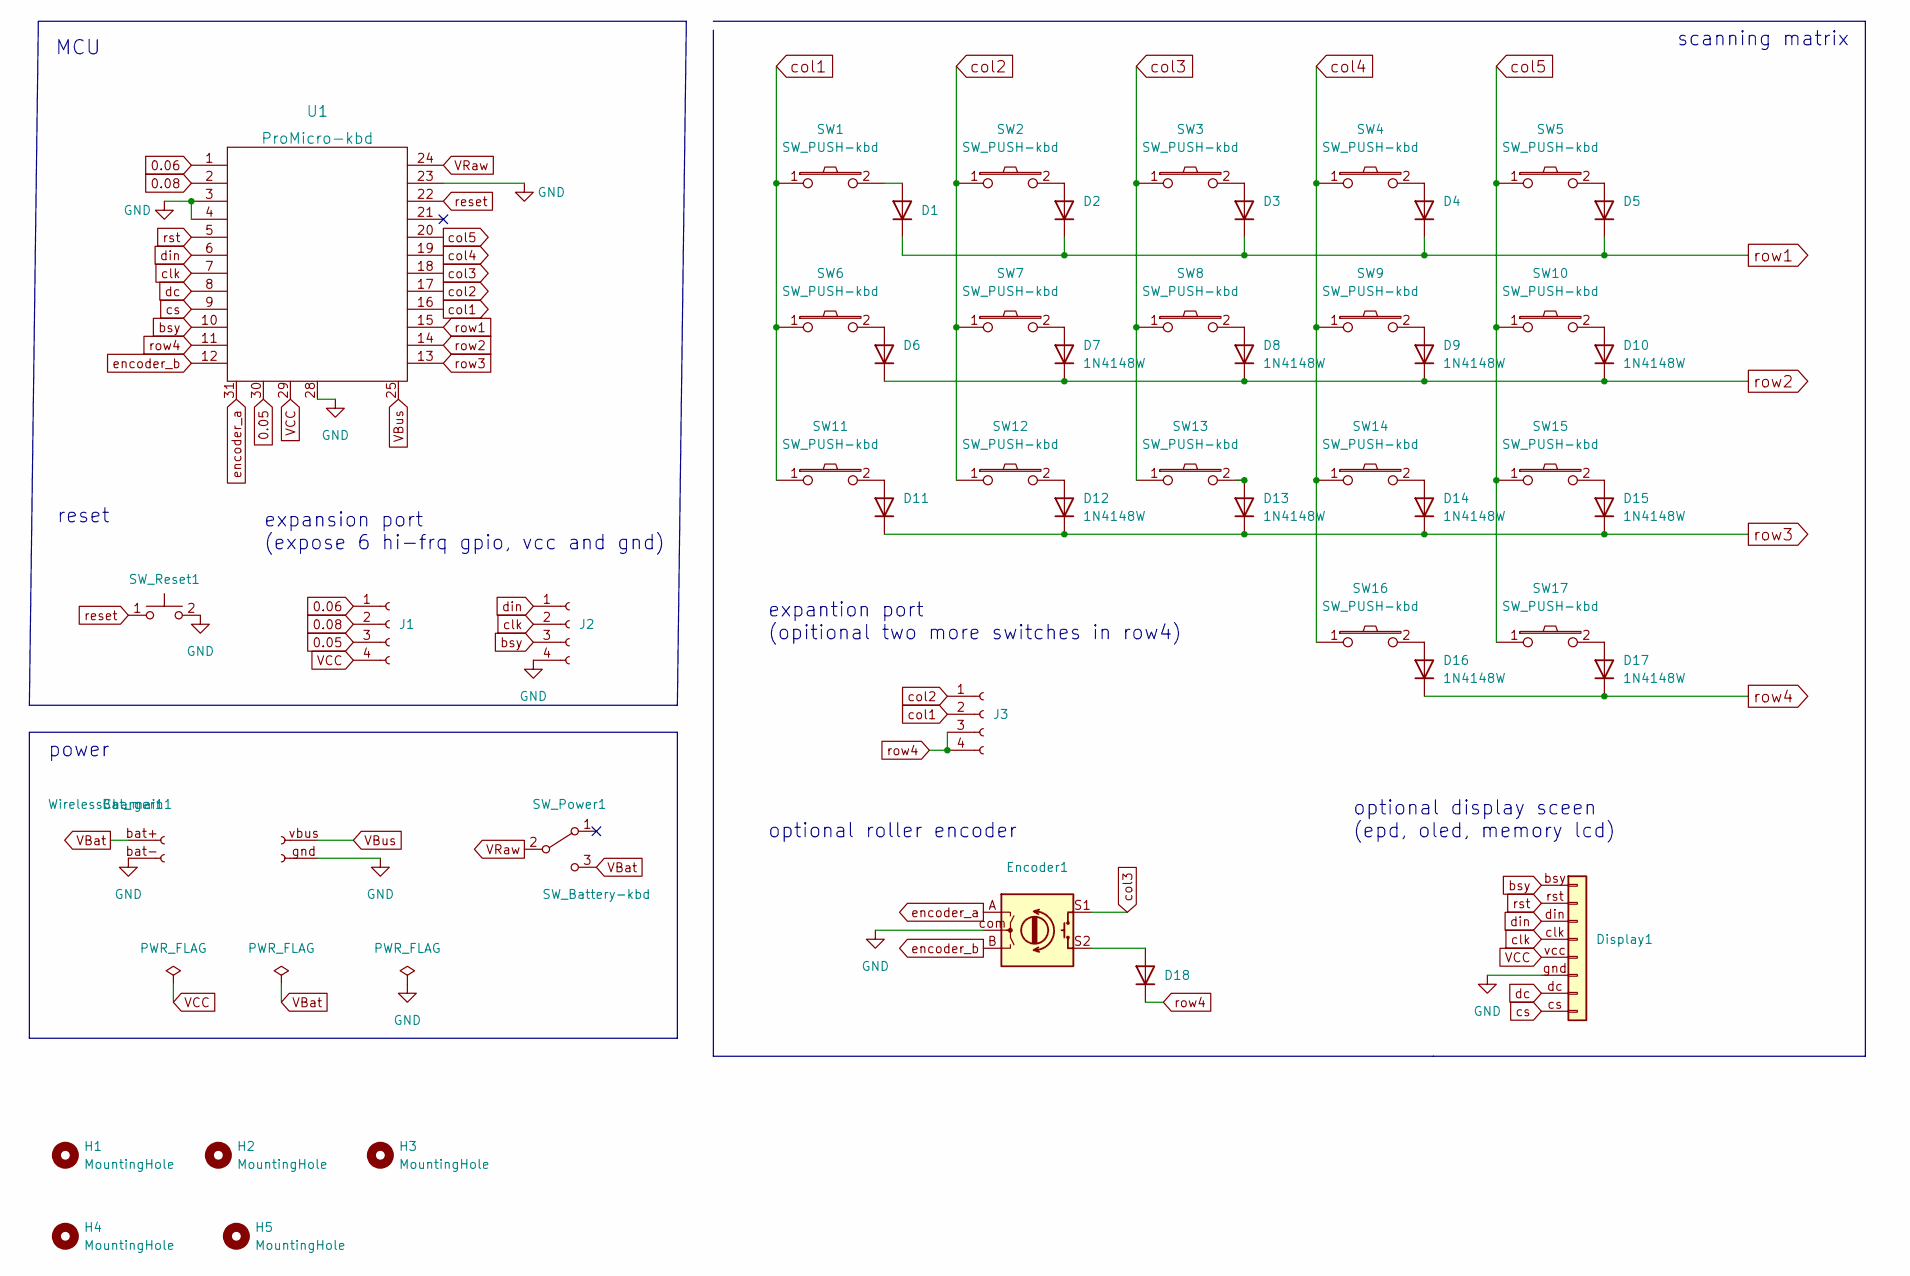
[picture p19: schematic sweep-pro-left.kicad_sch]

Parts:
Bat_main1: Conn_Battery_solderable; Molex_Panelmate_53780-0270_1x02-1MP_P1.25mm_Horizontal
D1, D2, D3, D4, D5, D6, D7, D8, D9, D10, D11, D12, D13, D14, D15, D16, D17, D18: 1N4148W; Diode
Display1: Conn_Display_general; Conn_EPD
Encoder1: RotaryEncoder; RollerEncoder_Panasonic_EVQWGD001
H1, H2, H3, H4, H5: MountingHole; MountingHole_3.2mm_M3_DIN965
J1, J2: Conn_01x04_Female; pogopin_1x4
J3: expantion1; pogopin_1x4
SW1, SW2, SW3, SW4, SW5, SW6, SW7, SW8, SW9, SW10, SW11, SW12, SW13, SW14, SW15, SW16, SW17: SW_PUSH-kbd; Kailh_Choc_Hotplug
SW_Power1: SW_Battery-kbd; SW_BSI10
SW_Reset1: SW_RESET-kbd; SW_Reset_vertical
U1: ProMicro-kbd; ProMacroLite_BackMount_Partial
WirelessCharger1: Conn_01x02_Female; VBus_pad_reversible

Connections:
0.05: J1.3, U1.30
0.06: J1.1, U1.1 (TX)
0.08: J1.2, U1.2 (RX)
GND: Bat_main1.bat- (Bat-), Display1.gnd (GND), Encoder1.com (COM), J2.4, SW_Reset1.2, U1.3 (GND), U1.4 (GND), U1.23 (GND), U1.28 (gnd), WirelessCharger1.gnd (GND)
unnamed: D1.2 (A), SW1.2
unnamed: D2.2 (A), SW2.2
unnamed: D3.2 (A), SW3.2
unnamed: D4.2 (A), SW4.2
unnamed: D5.2 (A), SW5.2
unnamed: D6.2 (A), SW6.2
unnamed: D7.2 (A), SW7.2
unnamed: D8.2 (A), SW8.2
unnamed: D9.2 (A), SW9.2
unnamed: D10.2 (A), SW10.2
unnamed: D11.2 (A), SW11.2
unnamed: D12.2 (A), SW12.2
unnamed: D13.2 (A), SW13.2
unnamed: D14.2 (A), SW14.2
unnamed: D15.2 (A), SW15.2
unnamed: D16.2 (A), SW16.2
unnamed: D17.2 (A), SW17.2
unnamed: D18.2 (A), Encoder1.S2
VBat: Bat_main1.bat+ (Bat+), SW_Power1.3 (C)
VBus: U1.25 (vbus), WirelessCharger1.vbus (VBUS)
VCC: Display1.vcc (VCC), J1.4, U1.29 (3.3V)
VRaw: SW_Power1.2 (B), U1.24 (RAW)
bsy: Display1.bsy (BSY), J2.3, U1.10 (E6)
clk: Display1.clk (CLK), J2.2, U1.7 (D4)
col1: J3.2, SW1.1, SW6.1, SW11.1, U1.16 (B1)
col2: J3.1, SW2.1, SW7.1, SW12.1, U1.17 (F7)
col3: Encoder1.S1, SW3.1, SW8.1, SW13.1, U1.18 (F6)
col4: SW4.1, SW9.1, SW14.1, SW16.1, U1.19 (F5)
col5: SW5.1, SW10.1, SW15.1, SW17.1, U1.20 (F4)
cs: Display1.cs (CS), U1.9 (D7)
dc: Display1.dc (DC), U1.8 (C6)
din: Display1.din (DIN), J2.1, U1.6 (SCL)
encoder_a: Encoder1.A, U1.31
encoder_b: Encoder1.B, U1.12 (B5)
reset: SW_Reset1.1, U1.22 (RST)
row1: D1.1 (K), D2.1 (K), D3.1 (K), D4.1 (K), D5.1 (K), U1.15 (B3)
row2: D6.1 (K), D7.1 (K), D8.1 (K), D9.1 (K), D10.1 (K), U1.14 (B2)
row3: D11.1 (K), D12.1 (K), D13.1 (K), D14.1 (K), D15.1 (K), U1.13 (B6)
row4: D16.1 (K), D17.1 (K), D18.1 (K), J3.3, J3.4, U1.11 (B4)
rst: Display1.rst (RST), U1.5 (SDA)

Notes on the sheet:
scanning matrix
optional roller encoder
reset
expansion port (expose 6 hi-frq gpio, vcc and gnd)
power
optional display sceen (epd, oled, memory lcd)
expantion port (opitional two more switches in row4)
MCU

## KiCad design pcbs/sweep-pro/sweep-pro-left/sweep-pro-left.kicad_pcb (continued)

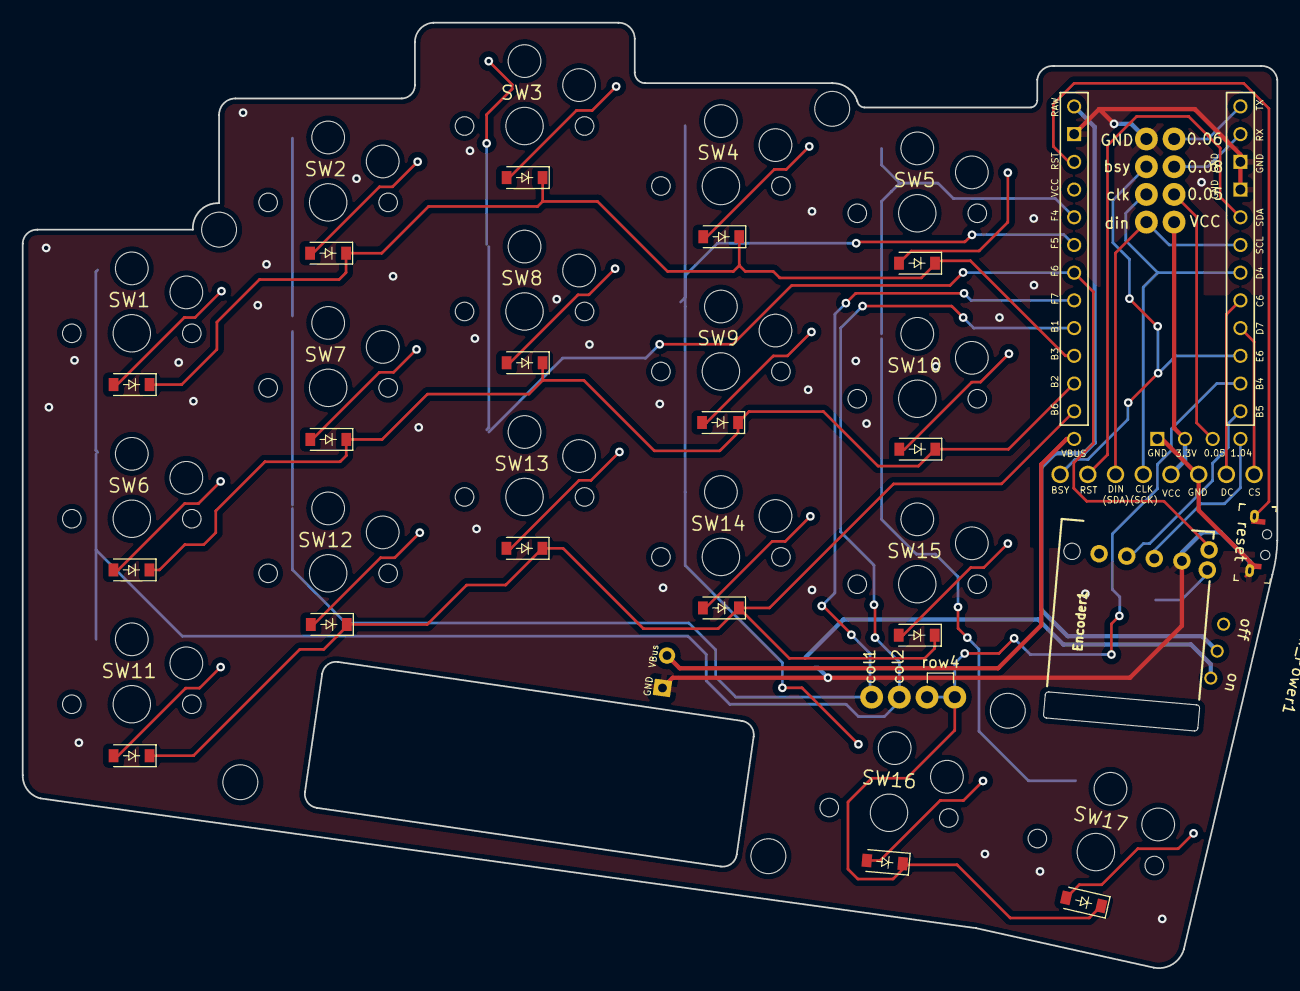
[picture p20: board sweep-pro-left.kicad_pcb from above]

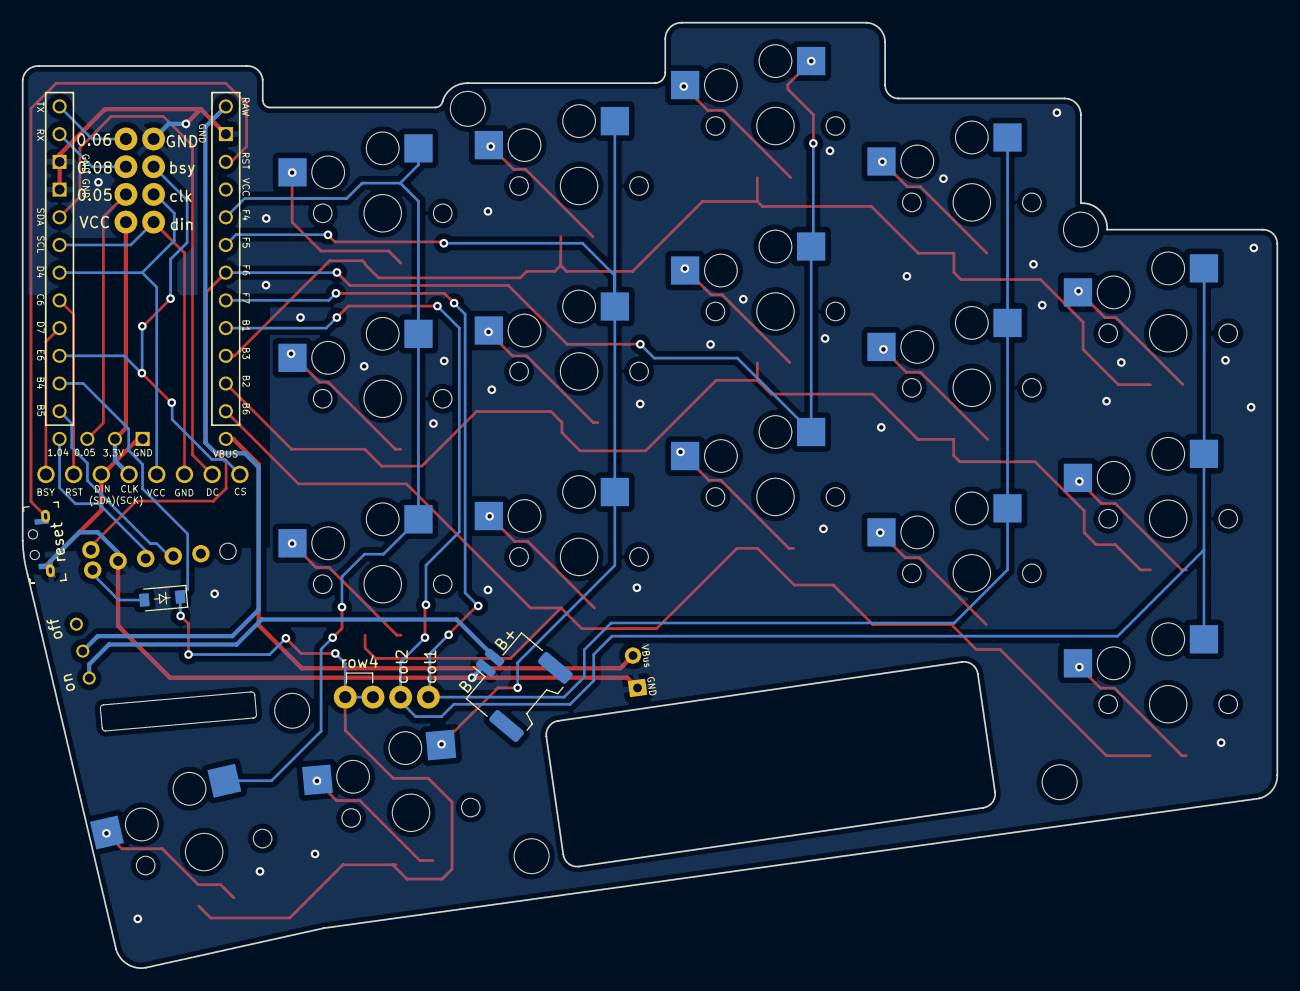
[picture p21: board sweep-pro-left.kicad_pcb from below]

Board: 2 copper layers, 115.0 x 86.7 mm, 50 parts (2 on the bottom side), 44 nets.

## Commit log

2022-06-05 A collection of keyboard pcbs designed by me
    [sweep-pro.kicad_pcb, sweep-pro.kicad_sch]
2022-06-06 init version of outline
    [sweep-pro.kicad_pcb]
2022-06-07 first version with complete routing
    [sweep-pro.kicad_pcb, sweep-pro.kicad_sch]
2022-06-07 outline and routing finished
    [sweep-pro.kicad_pcb, sweep-pro.kicad_sch]
2022-06-07 add 3d model
    [sweep-pro.kicad_pcb]
2022-06-08 add filled area (complete board)
    [sweep-pro.kicad_pcb, sweep-pro.kicad_sch]
2022-06-08 add 3d models
    [sweep-pro.kicad_pcb]
2022-06-08 change the position of battery connector for better case design. and change the angle of thumb cluster and board outline for better looking.
    [sweep-pro.kicad_pcb, sweep-pro.kicad_sch]
2022-06-10 add gerber zip
2022-06-11 change mouting hole diameter to 3.2mm
    [sweep-pro.kicad_pcb, sweep-pro.kicad_sch]
2022-06-11 change switch slot width from 14.1 to 14 mm
    [sweep-pro.kicad_pcb]
2022-06-22 add sweep-pro community edition
    [sweep-pro-ce.kicad_pcb, sweep-pro-ce.kicad_sch]
2022-06-27 sweepro-left intial finished version
    [sweep-pro-left.kicad_pcb]
2022-06-28 sweepro v2
    1. add three expansion ports (pogopin connection)
    2. remev battery extra port
    3. use nrfmacro-lite partial footprint
    4. new power switch
    5. re-position reset button
    6. seperate board for left and right split
    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
    [sweep-pro-left.kicad_pcb, sweep-pro-right.kicad_pcb, sweep-pro-right.kicad_sch]
2022-06-29 finish left-split of corne-pro using nrfmicro as mcu
    [corne-pro-nrfmicro.kicad_pcb, corne-pro-nrfmicro.kicad_sch]
2022-06-29 add battery switch slot
    [corne-pro-nrfmicro.kicad_pcb]
2022-06-29 add a con port using jst ach connector
    [left.kicad_pcb, left.kicad_sch]
2022-06-29 add gerber zip file
    [left.kicad_pcb, left.kicad_sch]
2022-07-03 remove ground fill around anntena and tweak the anntena hole
    [left.kicad_pcb]
2022-07-03 clean up
    [corne-pro-nrfmicro.kicad_pcb, corne-pro-nrfmicro.kicad_sch]
2022-07-04 finish right split of corne-pro
    [left.kicad_pcb, right.kicad_pcb, right.kicad_sch]
2022-07-06 add sweepro adaptor board
    [sweep-pro-adapator.kicad_pcb, sweep-pro-adapator.kicad_sch, sweep-pro-left.kicad_pcb]
2022-07-06 update gerbers
2022-07-08 remove extra swithes from sweepro-adaptor due to jlc extra charge
    [sweep-pro-adapator.kicad_pcb]
2022-07-08 single swithes pcb
    [sweepro-single-swithes.kicad_pcb, sweepro-single-swithes.kicad_sch]
2022-07-21 [sweep-pro] correct the position of the encoder in right split
    [sweep-pro-right.kicad_pcb]
2022-08-13 backup :
    [sweep-pro-right.kicad_pcb]
2022-08-13 [sweep-pro] modify the encoder position on right side and add the correct gerber file
2022-08-13 [sweep-pro] rename the outdated right gerber
2022-09-02 [change] hotplug socket outline, does not affect pcb fabrication file
    [left.kicad_pcb, right.kicad_pcb, sweep-pro-left.kicad_pcb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]
2022-09-17 [trackball-right] init version of valid schematics
    [encoder.kicad_sch, keyboard.kicad_sch, mcu_e73.kicad_sch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]
2022-09-21 init version with integrated trackball in thumb position
    [encoder.kicad_sch, keyboard.kicad_sch, mcu_e73.kicad_sch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]
2022-09-22 add blade keyboard (right, 38 keys, 5x3+2+2)
    [blade-right.kicad_pcb, blade-right.kicad_sch, encoder.kicad_sch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]
2022-09-23 add blade-right with trackball in thumb position
    [blade-right-trackball.kicad_pcb, blade-right-trackball.kicad_sch, encoder.kicad_sch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]
2022-09-23 add blade right with only keys
    [blade-right-key.kicad_pcb, blade-right-key.kicad_sch]
2022-09-23 add blade right with only keys (3x5)
    [blade-right-key-3x5.kicad_pcb, blade-right-key-3x5.kicad_sch, encoder.kicad_sch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]
2022-09-23 add blade with trackball on the external thumb position
    [blade-right-trackball-external.kicad_pcb, blade-right-trackball-external.kicad_sch, encoder.kicad_sch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]
2022-11-04 seperate directory for breakout pcbs
    [encoder.kicad_pcb, pmw3610.kicad_pcb]
2023-03-10 update readme. add new photo
    [blade-right-trackball-3x5.kicad_pcb]
